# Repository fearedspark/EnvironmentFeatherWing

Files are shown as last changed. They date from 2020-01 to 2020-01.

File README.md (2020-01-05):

# Environmental Sensor Board Project

**`PCB Software`**: `KiCad`

This project is a Feather Wing board hosting a tempertature/humidity sensor and a volatile organic compounds/equivalent CO2 sensor from sensirion.  
This is also my first KiCad project.

## Important Parts

- T/RH Sensor: SHT31-DIS-F ([Datasheet](https://www.sensirion.com/fileadmin/user_upload/customers/sensirion/Dokumente/0_Datasheets/Humidity/Sensirion_Humidity_Sensors_SHT3x_Datasheet_digital.pdf))
- VOC/eCO2 Sensor: SGP30 ([Datasheet](https://www.sensirion.com/fileadmin/user_upload/customers/sensirion/Dokumente/0_Datasheets/Gas/Sensirion_Gas_Sensors_SGP30_Datasheet.pdf))
- 1.8V LDO Regulator: MCP1754S-1802E/CB ([Datasheet](http://ww1.microchip.com/downloads/en/DeviceDoc/20002276C.pdf))

## Power Supply

The sensors are powered from the 3.3V rail available on the feather wing headers.
The SGP30 sensor has an LDO to provide it with 1.8V.

## BOM

|Designator(s) |Quantity|Manufacturer |Part Number |Description |Value|Tolerance|Rating|Package |Type|Note|
|---|:---:|---|---|---|-----|---|---|---|----|----|
|U1 |1 |Sensirion AG |SHT31-DIS-F |Temperature/Humidity I2C Sensor| | | |8-DFN (2.5x2.5)  |SMT | |
|U2 |1 |Microchip Technology|MCP1754ST-1802E/CB|1.8V LDO Voltage Regulator | | | |SOT-23A-3 |SMT | |
|U3 |1 |Sensirion AG |SGP30 |TVOS/CO2eq I2C Sensor | | | |6-DFN (2.45x2.45)|SMT | |
|Q1, Q2 |2 |ON Semiconductor |BSS138 |N-Channel MOSFET, 50V, 220mA | | | |SOT-23 |SMT | |
|C1, C3, C4 |3 | | |10µF, 6.3V, 0805 |10µF |≤±20% |≥6.3V |0805 |SMT | |
|C2, C5, C6 |3 | | |100nF, 6.3V, 0603 |100nF|≤±20% |≥6.3V |0603 |SMT | |
|R1, R2, R3, R4, R5, R6|6 | | |10kΩ, ±5%, 0603 |10kΩ |≤±5% | |0603 |SMT | |

## TODO

- Might add an absolute pressure sensor in a next revision

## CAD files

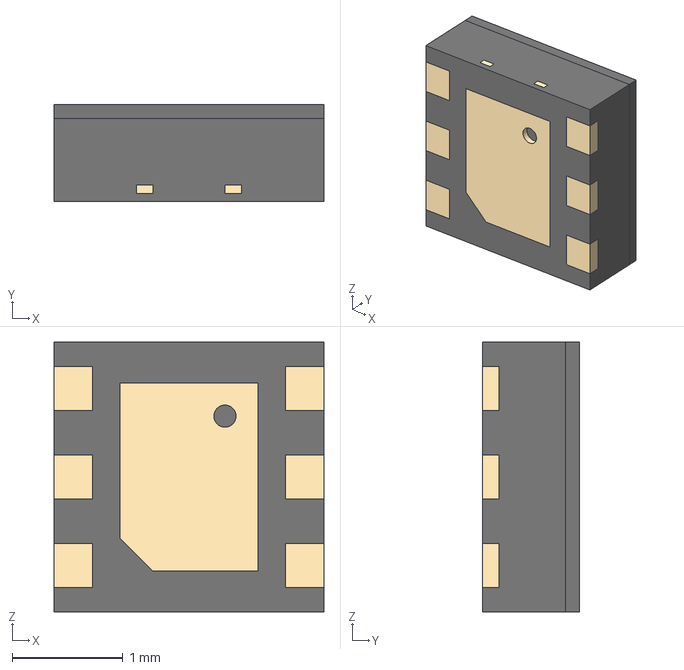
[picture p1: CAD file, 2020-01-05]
SGP30.step
2.44 x 0.88 x 2.44 mm

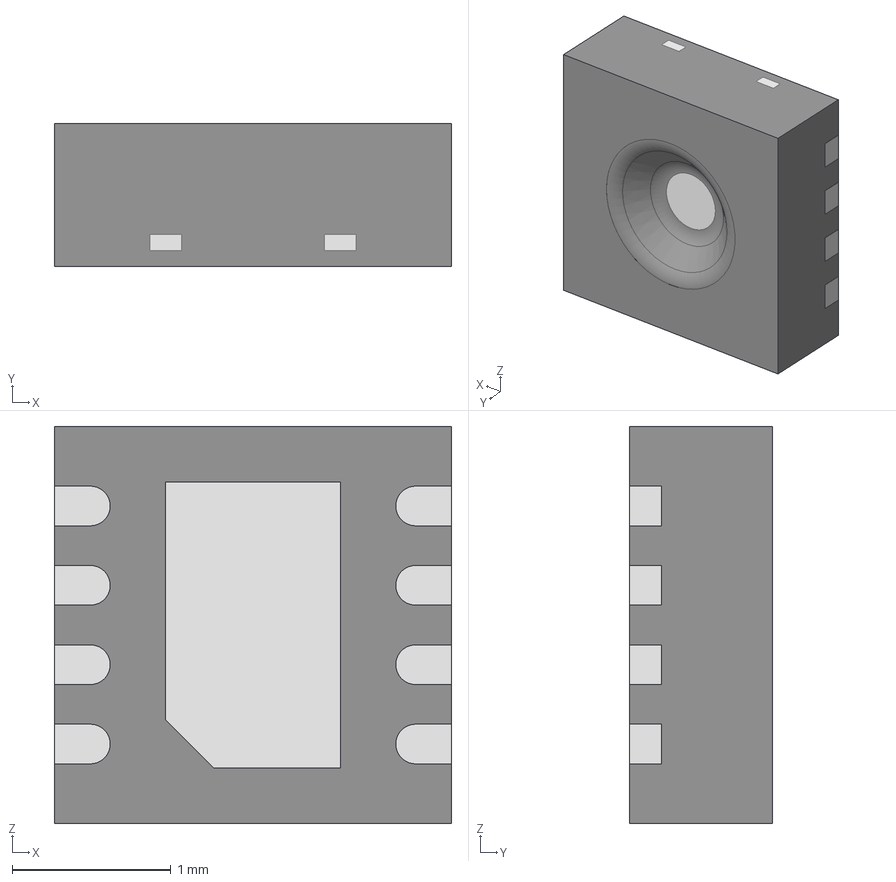
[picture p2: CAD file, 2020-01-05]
SHT31.step
2.50 x 0.901 x 2.50 mm

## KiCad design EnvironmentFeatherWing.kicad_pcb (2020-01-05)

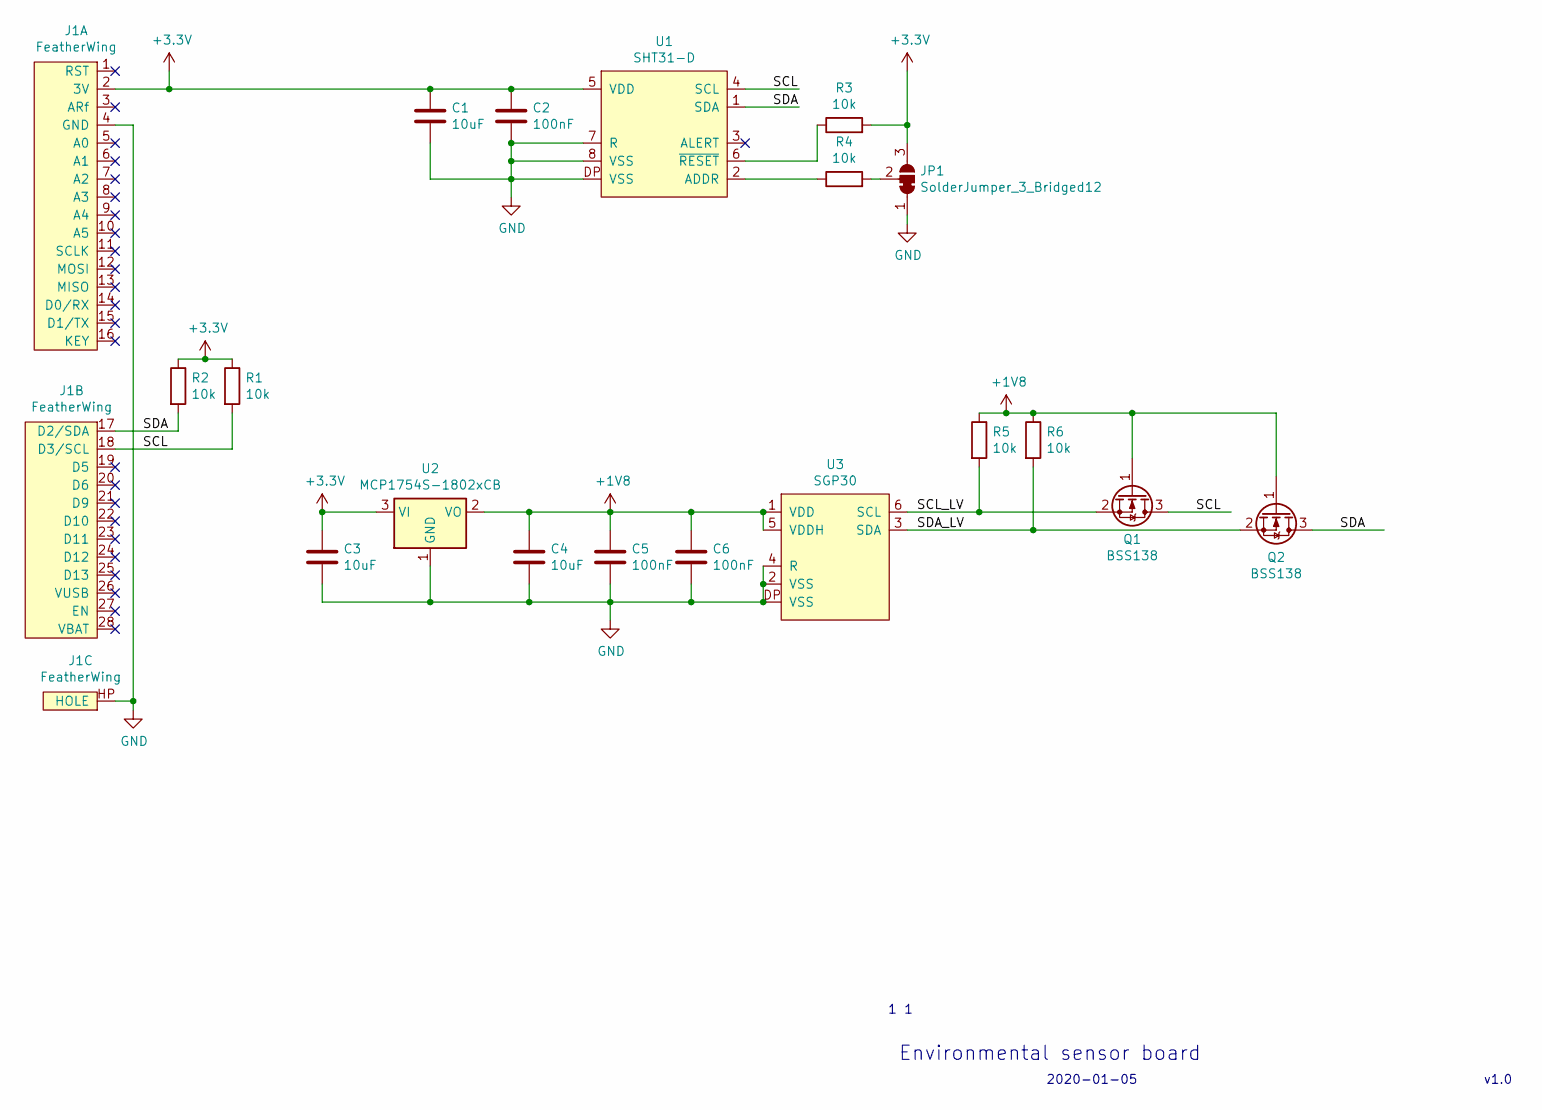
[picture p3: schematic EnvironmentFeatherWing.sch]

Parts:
C1, C3, C4: 10uF; C_0805_2012Metric
C2, C5, C6: 100nF; C_0603_1608Metric
J1: FeatherWing
JP1: SolderJumper_3_Bridged12; SolderJumper-3_P1.3mm_Bridged12_Pad1.0x1.5mm
Q1, Q2: BSS138; SOT-23
R1, R2, R3, R4, R5, R6: 10k; R_0603_1608Metric
U1: SHT31-D; DFN-8-2.5x2.5x0.9
U2: MCP1754S-1802xCB; SOT-23
U3: SGP30; DFN-6-2.45x2.45x0.9

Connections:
+1V8: C4.1, C5.1, C6.1, Q1.1 (G), Q2.1 (G), R5.1, R6.1, U2.2 (VO), U3.1 (VDD), U3.5 (VDDH)
+3V3: C1.1, C2.1, C3.1, J1.2 (3V), JP1.3 (B), R1.1, R2.1, R3.2, U1.5 (VDD), U2.3 (VI)
/SCL: J1.18 (D3/SCL), Q1.3 (D), R1.2, U1.4 (SCL)
/SCL_LV: Q1.2 (S), R5.2, U3.6 (SCL)
/SDA: J1.17 (D2/SDA), Q2.3 (D), R2.2, U1.1 (SDA)
/SDA_LV: Q2.2 (S), R6.2, U3.3 (SDA)
GND: C1.2, C2.2, C3.2, C4.2, C5.2, C6.2, J1.4 (GND), J1.HP (HOLE), JP1.1 (A), U1.7 (R), U1.8 (VSS), U1.DP (VSS), U2.1 (GND), U3.2 (VSS), U3.4 (R), U3.DP (VSS)
unnamed: JP1.2 (C), R4.2
unnamed: R3.1, U1.6 (~RESET)
unnamed: R4.1, U1.2 (ADDR)

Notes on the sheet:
Environmental sensor board
v1.0
2020-01-05

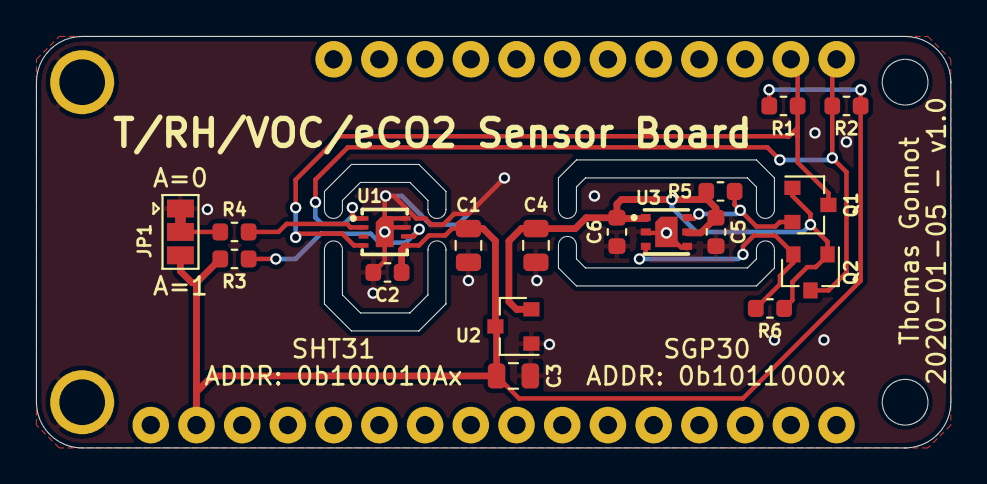
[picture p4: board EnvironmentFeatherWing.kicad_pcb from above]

Board: 2 copper layers, 50.8 x 22.9 mm, 19 parts (0 on the bottom side), 10 nets.

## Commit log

2020-01-05 First revision
    [EnvironmentFeatherWing.kicad_pcb, EnvironmentFeatherWing.sch, SGP30.step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]
2020-01-05 Updated README with BOM
2020-01-05 Added missing library cache file
    [EnvironmentFeatherWing.kicad_pcb, EnvironmentFeatherWing.sch]
